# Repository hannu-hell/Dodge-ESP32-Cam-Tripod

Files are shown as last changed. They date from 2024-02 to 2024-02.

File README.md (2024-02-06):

# Dodge-ESP32-Cam-Tripod
Dodge is an ESP32 Cam based novel tripod design.  Feel free to check out full build instructions on Instructables website - https://www.instructables.com/Dodge-ESP32-Cam-Based-Tripod/

## Setting Neutral Position for all six servos
You need to get the neutral positions for all servos set before uploading the code for Dodge to move correctly.  I have included an image with Dodge in its neutral position and the angles the servos should be at those positions.
Once done with setting the neutral angles the rest of the moves by Dodge will be calculated correctly.

<ins><strong>Right Leg Top Servo (rAT)</strong></ins>\
GPIO Pin - IO 12\
Neutral Position - 60 degrees\
Leg Upwards - Increase degrees\
Leg Downwards - Decrease degrees

<ins><strong>Left Leg Top Servo (lAT)</strong></ins>\
GPIO Pin - IO 13\
Neutral Position - 105 degrees\
Leg Upwards - Decrease degrees\
Leg Downwards - Increase degrees

<ins><strong>Right Leg Bottom Servo (rAB)</strong></ins>\
GPIO Pin - IO 14\
Neutral Position - 90 degrees\
Leg Upwards - Increase degrees\
Leg Downwards - Decrease degrees

<ins><strong>Left Leg Bottom Servo (lAB)</strong></ins>\
GPIO Pin - IO 15\
Neutral Position - 95 degrees\
Leg Upwards - Decrease degrees\
Leg Downwards - Increase degrees

<ins><strong>Pinion Servo (mL)</strong></ins>\
GPIO Pin - IO 2\
Neutral Position - 107 degrees\
Leg Upwards - Decrease degrees\
Leg Downwards - Increase degrees

<ins><strong>Support Foot (bS)</strong></ins>\
GPIO Pin - IO 4\
Neutral Position - 90 degrees\
Rotation angle between 20 degrees and 180 degrees

## Uploading Code
When uploading code to the ESP32 Cam module you need the ESP32 Cam-MB which has the boot loader to upload code. You need to press the IO 0 button on the ESP32 Cam-MB and then the RST button on the ESP32 module to put the board to accept code uploads. Apart from that you will also need to download ESP32Servo library by Kevin Harrington/John K. Bennett from the Library manager in Arduino IDE.

## Powering up
In the code file update to your desired password to connect to Dodge and once the code has been uploaded you can see it visible as Dodge-Tripod on the WIFI network. After you upload the code make sure to reset the ESP32 Cam module by pressing the RST button on the back. Connect to Dodge-Tripod and then open up a browser and in the url enter 192.168.4.1 on your phone/computer to connect to the Dodge Control App. Make sure to power up the Primary and Secondary Batteries and then your good to go. Power on the primary battery by connecting the barrel jack and turning the small slide switch on the bottom of Dodge's head, and then you can power on the secondary battery by connecting the battery to the buck converter module.

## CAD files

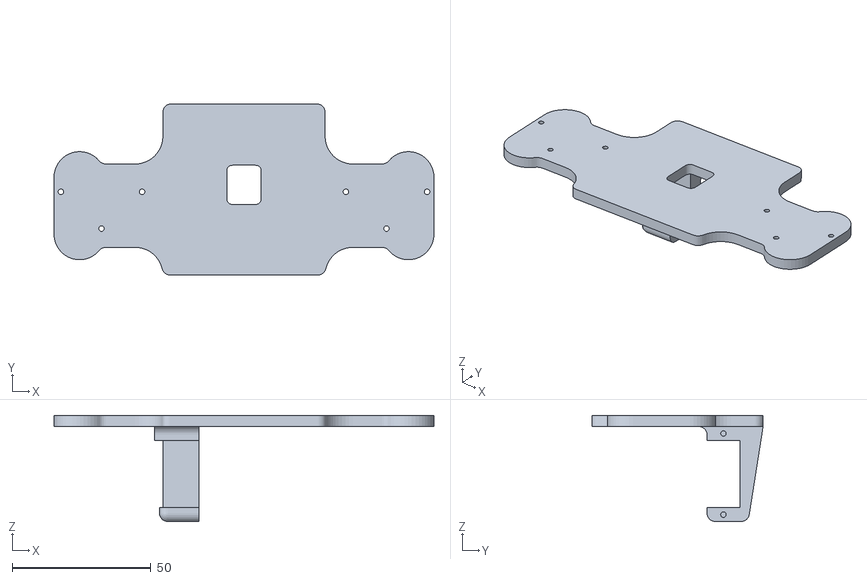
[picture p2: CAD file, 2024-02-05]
Top_Plate.stl
136.8 x 61.6 x 38.2

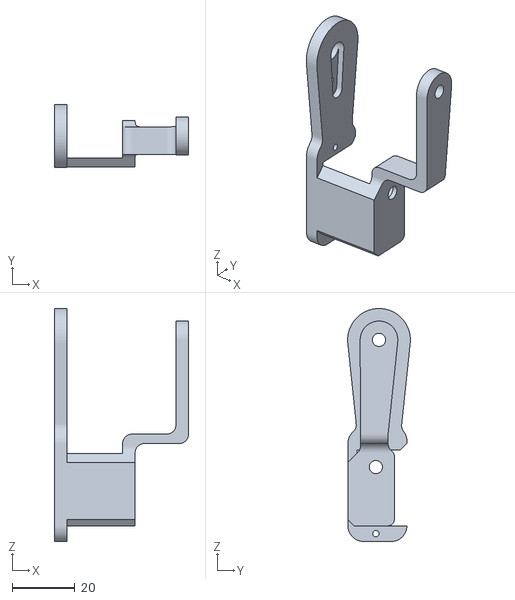
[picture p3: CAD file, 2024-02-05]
Upper_Leg.stl
42.7 x 20.0 x 74.2

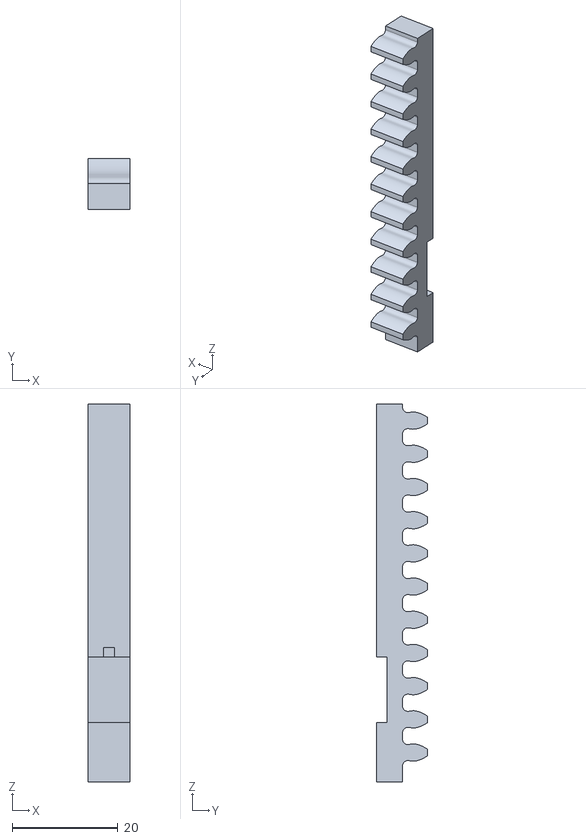
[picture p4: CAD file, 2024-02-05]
Rack.stl
8.00 x 9.72 x 71.5

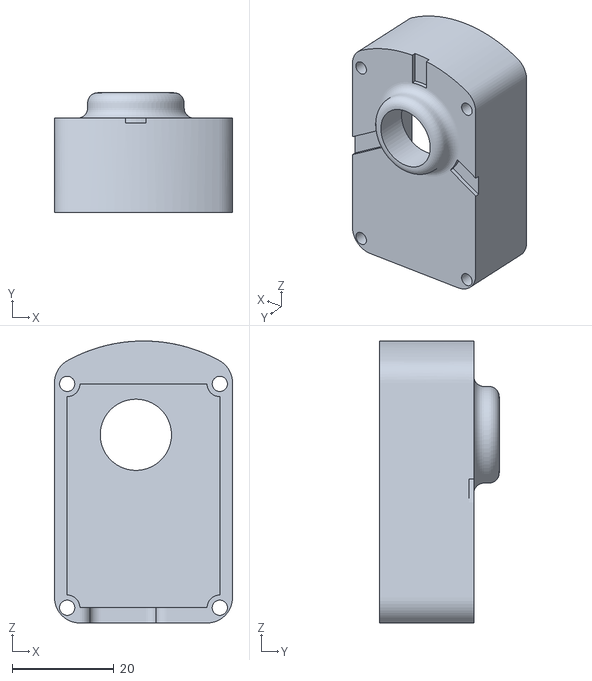
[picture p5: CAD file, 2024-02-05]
Head_Front.stl
35.0 x 23.5 x 55.4

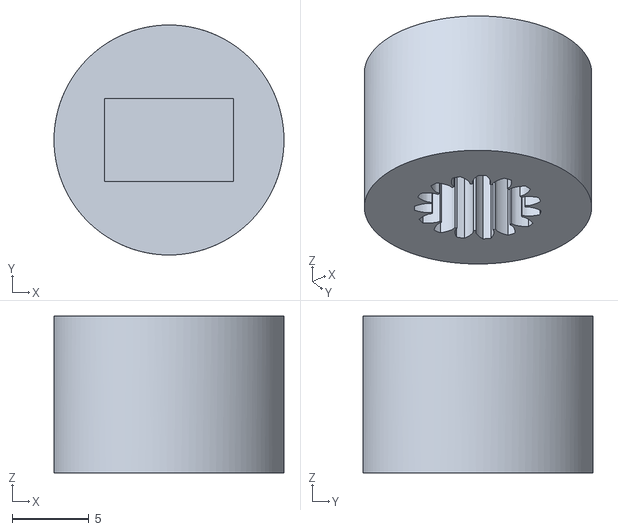
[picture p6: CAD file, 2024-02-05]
Collar.stl
15.0 x 15.0 x 10.2

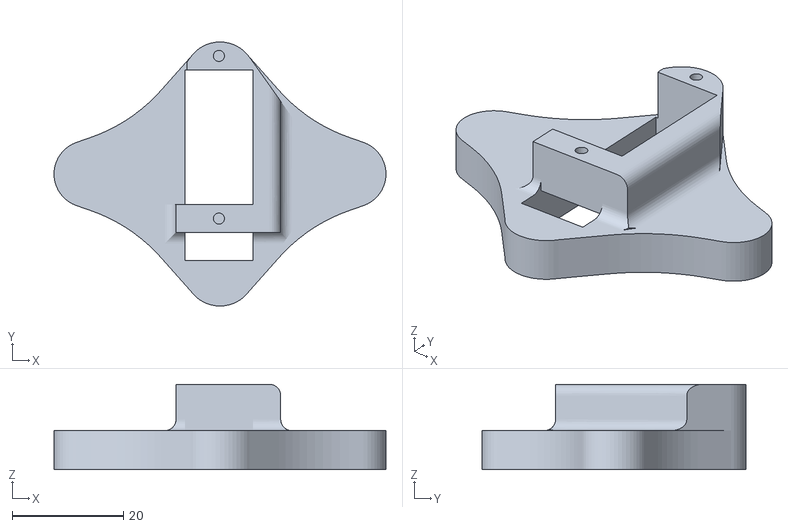
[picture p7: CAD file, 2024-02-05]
Support_Feet.stl
59.6 x 47.4 x 15.3

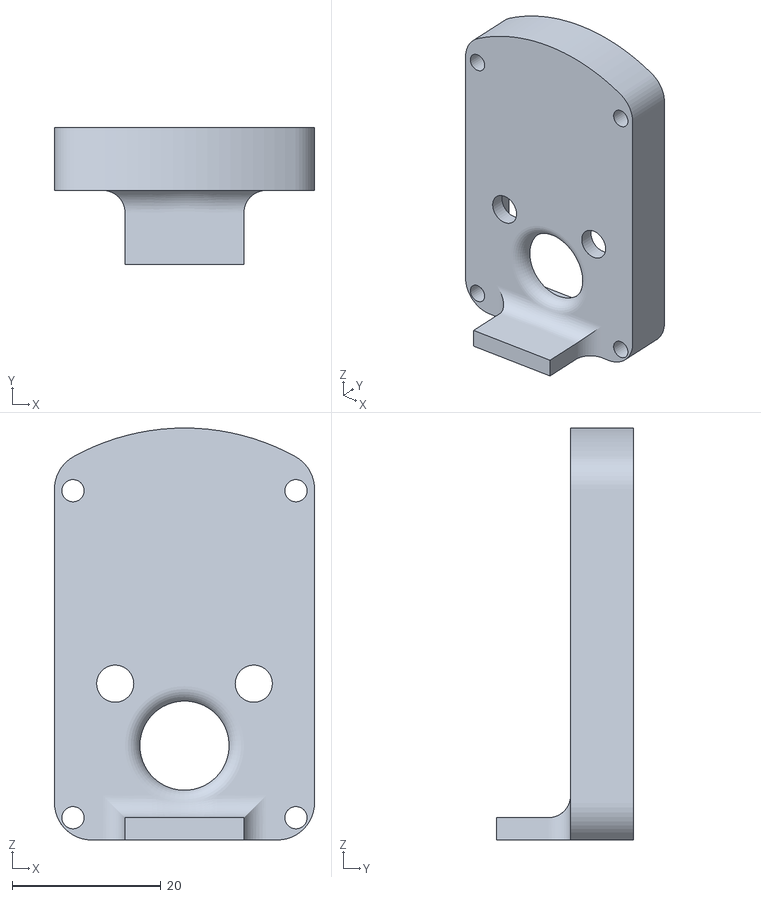
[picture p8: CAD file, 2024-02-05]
Head_Back.stl
35.0 x 18.5 x 55.4

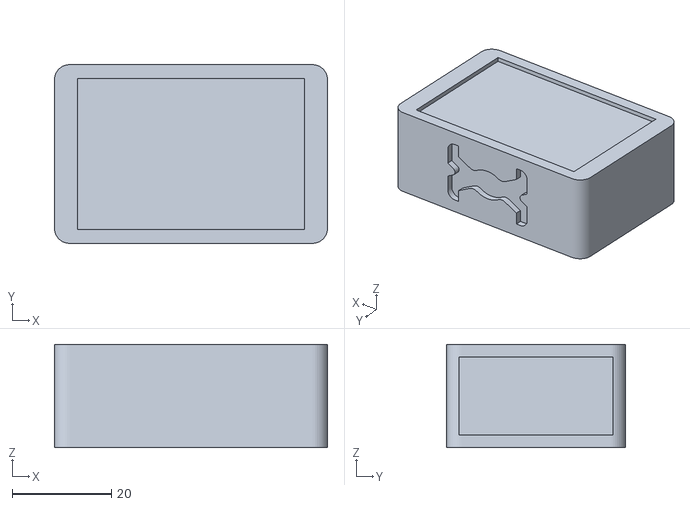
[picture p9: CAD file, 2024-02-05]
Battery_Compartment.stl
55.0 x 36.0 x 20.8

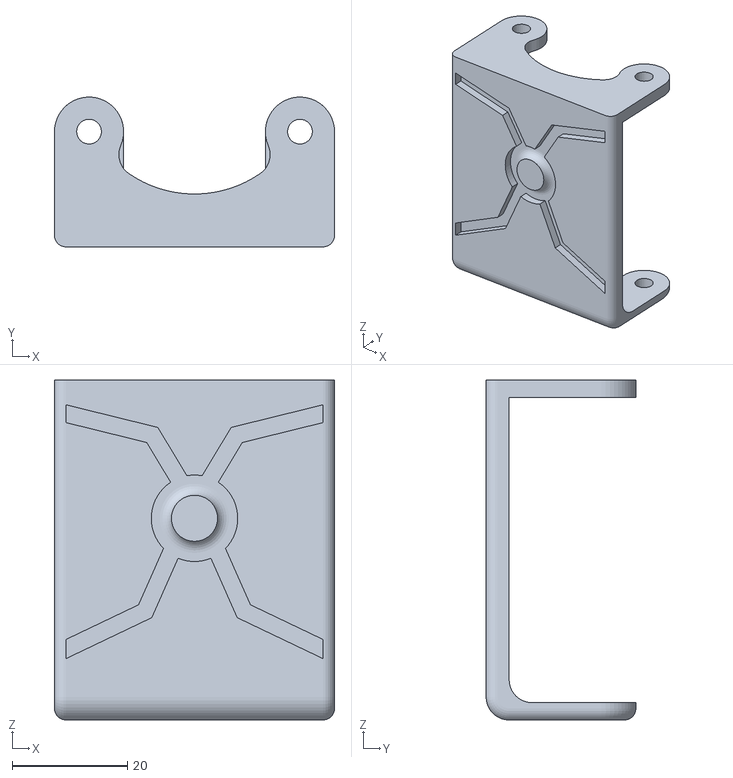
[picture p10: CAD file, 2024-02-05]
Bearing_Frame.stl
48.6 x 26.0 x 59.0

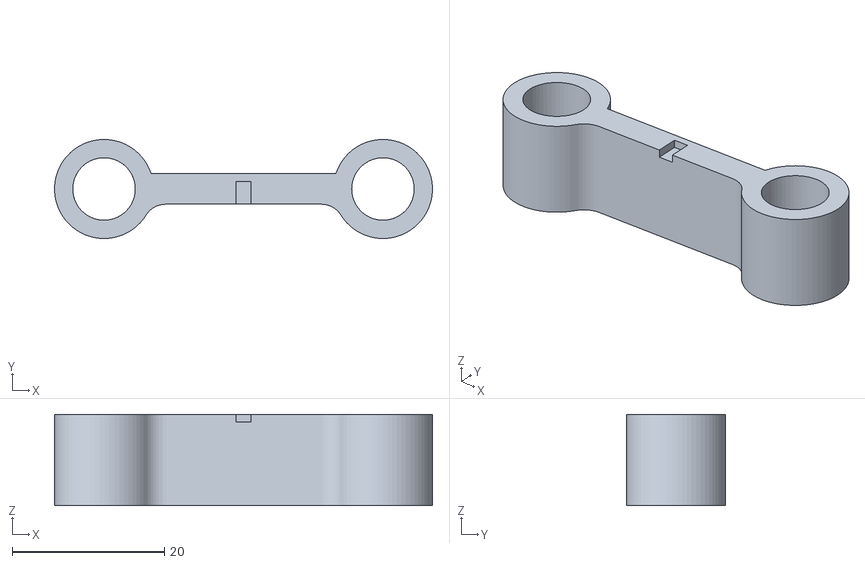
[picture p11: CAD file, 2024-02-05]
Bearing_Holder.stl
49.6 x 13.0 x 12.0

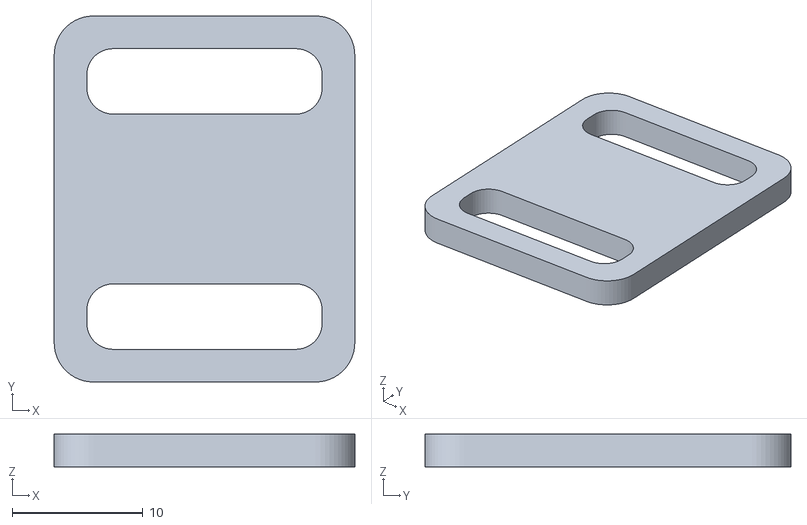
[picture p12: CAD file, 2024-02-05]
Buck_Casing_Lid.stl
23.0 x 28.0 x 2.50

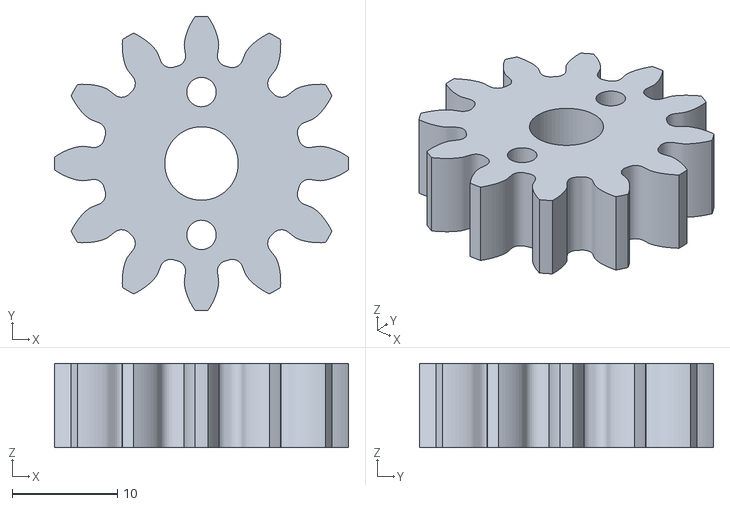
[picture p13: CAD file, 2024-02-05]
Pinion.stl
28.0 x 28.0 x 8.00

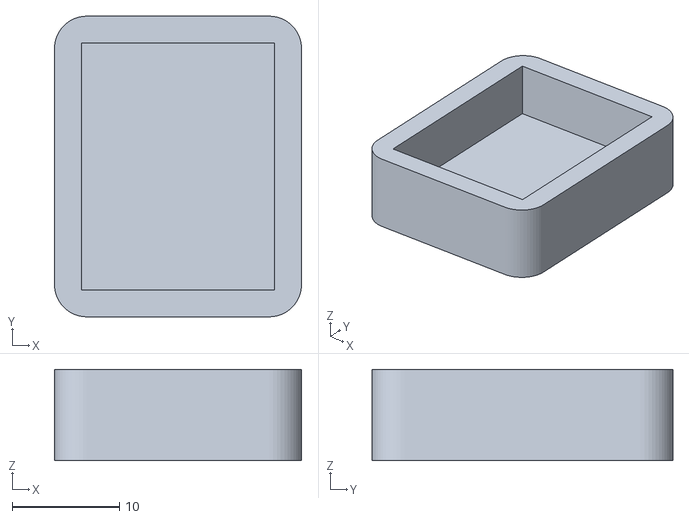
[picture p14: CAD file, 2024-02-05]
Buck_Convertor_Casing.stl
23.0 x 28.0 x 8.50

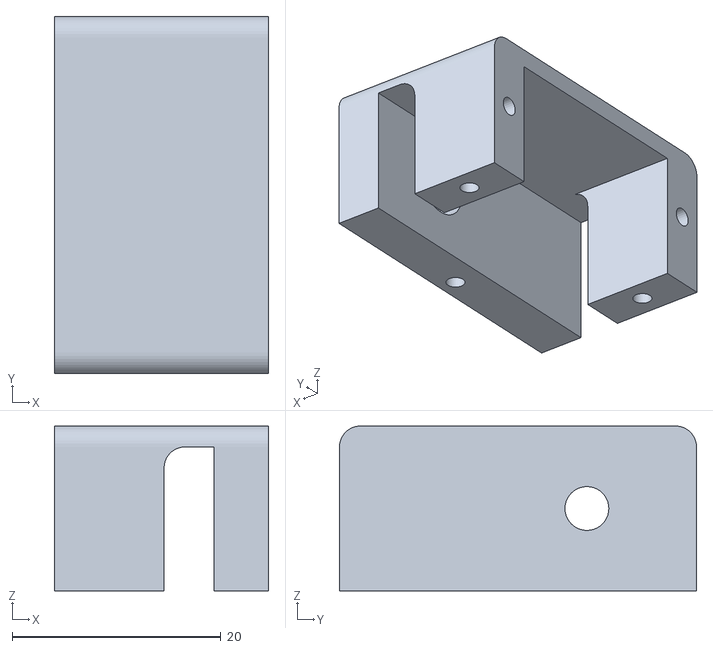
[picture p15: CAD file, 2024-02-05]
Left_Shoulder.stl
20.5 x 34.2 x 15.8

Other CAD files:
Feet.stl
Coupler_Gear.stl
Lower_Leg.stl
Primary_Battery_Compartment.stl
Right_Shoulder.stl

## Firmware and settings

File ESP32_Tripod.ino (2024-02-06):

#include "esp_camera.h"
#include <WiFi.h>
#include "esp_timer.h"
#include "img_converters.h"
#include "Arduino.h"
#include "fb_gfx.h"
#include "soc/soc.h"             // disable brownout problems
#include "soc/rtc_cntl_reg.h"    // disable brownout problems
#include "esp_http_server.h"
#include <ESP32Servo.h>

// Replace with your preffered password
const char* ssid = "Dodge-Tripod";
const char* password = "hannu1234";

#define PART_BOUNDARY "123456789000000000000987654321"

#define PWDN_GPIO_NUM     32
#define RESET_GPIO_NUM    -1
#define XCLK_GPIO_NUM      0
#define SIOD_GPIO_NUM     26
#define SIOC_GPIO_NUM     27

#define Y9_GPIO_NUM       35
#define Y8_GPIO_NUM       34
#define Y7_GPIO_NUM       39
#define Y6_GPIO_NUM       36
#define Y5_GPIO_NUM       21
#define Y4_GPIO_NUM       19
#define Y3_GPIO_NUM       18
#define Y2_GPIO_NUM        5
#define VSYNC_GPIO_NUM    25
#define HREF_GPIO_NUM     23
#define PCLK_GPIO_NUM     22

// Servo definitions

/* 
  bS -> Support Feet Base Servo
  rAT -> Right Leg Top Servo
  lAT -> Left Leg Top Servo
  rAB -> Right Leg Bottom Servo
  lAB -> Left Leg Bottom Servo
  mL -> Pinion Servo

*/

Servo bS;
Servo rAT;
Servo lAT;
Servo rAB;
Servo lAB;
Servo mL;


/* 
These are the neutral positions for the servos. The Upper (rAT and lAT) and Lower (rAB and LAB) Legs should be 90 degrees to the ground when set to these neutral positions (nRAT, nRAB, nLAT and nLAB).
The pinion servo angles should be mLD when lowered to its extreme (touching the ground) and mLU when raised to its upper limit (support foot raised up).  After you
adjust the servo positions to these angles the rest of the angles will be calculated accurately.
You can have a look at the image on this repo showing Dodge in its neutral position to have a clear idea. 
*/
int nRAT = 60;
int nRAB = 90;
int nLAT = 105;
int nLAB = 95;
int mLD = 165;
int mLU = 50;

int rotPos = 90;  // Rotation angle of the support foot servo
bool flip = false;
bool rightFlip = false;
bool leftFlip = true;
bool moveUp = false;
bool moveDown = false;
bool showMoves = false;

static const char* _STREAM_CONTENT_TYPE = "multipart/x-mixed-replace;boundary=" PART_BOUNDARY;
static const char* _STREAM_BOUNDARY = "\r\n--" PART_BOUNDARY "\r\n";
static const char* _STREAM_PART = "Content-Type: image/jpeg\r\nContent-Length: %u\r\n\r\n";

httpd_handle_t camera_httpd = NULL;
httpd_handle_t stream_httpd = NULL;

static const char PROGMEM INDEX_HTML[] = R"rawliteral(
<html>
  <head>
    <title>ESP32-CAM Robot</title>
    <meta name="viewport" content="width=device-width, initial-scale=1">
    <style>
      body { font-family: Arial; text-align: center; margin:0px auto; padding-top: 30px;}
      table { margin-left: auto; margin-right: auto; }
      td { padding: 8 px; }
      .button {
        background-color: #2f4468;
        border: none;
        color: white;
        padding: 10px 20px;
        text-align: center;
        text-decoration: none;
        display: inline-block;
        font-size: 18px;
        margin: 6px 3px;
        cursor: pointer;
        -webkit-touch-callout: none;
        -webkit-user-select: none;
        -khtml-user-select: none;
        -moz-user-select: none;
        -ms-user-select: none;
        user-select: none;
        -webkit-tap-highlight-color: rgba(0,0,0,0);
      }
      img {  width: auto ;
        max-width: 100% ;
        height: auto ; 
      }
    </style>
  </head>
  <body>
    <h1>Dodge-Tripod</h1>
    <img src="" id="photo" >
    <table>
      <tr><td colspan="3" align="center"><button class="button" onmousedown="toggleCheckbox('up');" ontouchstart="toggleCheckbox('up');">Up</button></td></tr>
      <tr><td align="center"><button class="button" onmousedown="toggleCheckbox('left');" ontouchstart="toggleCheckbox('left');">Left</button></td><td align="center"></td><td align="center"><button class="button" onmousedown="toggleCheckbox('right');" ontouchstart="toggleCheckbox('right');">Right</button></td></tr>
      <tr><td colspan="3" align="center"><button class="button" onmousedown="toggleCheckbox('down');" ontouchstart="toggleCheckbox('down');">Down</button></td></tr>
      <tr><td align="center"><button class="button" onmousedown="toggleCheckbox('l-turn');" ontouchstart="toggleCheckbox('l-turn');">L-Turn</button></td><td align="center"></td><td align="center"><button class="button" onmousedown="toggleCheckbox('r-turn');" ontouchstart="toggleCheckbox('r-turn');">R-Turn</button></td></tr>
      <tr><td align="center"><button class="button" onmousedown="toggleCheckbox('moves');" ontouchstart="toggleCheckbox('moves');">Moves</button></td><td align="center"></td><td align="center"><button class="button" onmousedown="toggleCheckbox('flip');" ontouchstart="toggleCheckbox('flip');">Flip</button></td></tr>                  
    </table>
   <script>
   function toggleCheckbox(x) {
     var xhr = new XMLHttpRequest();
     xhr.open("GET", "/action?go=" + x, true);
     xhr.send();
   }
   window.onload = document.getElementById("photo").src = window.location.href.slice(0, -1) + ":81/stream";
  </script>
  </body>
</html>
)rawliteral";

static esp_err_t index_handler(httpd_req_t *req){
  httpd_resp_set_type(req, "text/html");
  return httpd_resp_send(req, (const char *)INDEX_HTML, strlen(INDEX_HTML));
}

static esp_err_t stream_handler(httpd_req_t *req){
  camera_fb_t * fb = NULL;
  esp_err_t res = ESP_OK;
  size_t _jpg_buf_len = 0;
  uint8_t * _jpg_buf = NULL;
  char * part_buf[64];

  res = httpd_resp_set_type(req, _STREAM_CONTENT_TYPE);
  if(res != ESP_OK){
    return res;
  }

  while(true){
    fb = esp_camera_fb_get();
    if (!fb) {
      Serial.println("Camera capture failed");
      res = ESP_FAIL;
    } else {
      if(fb->width > 400){
        if(fb->format != PIXFORMAT_JPEG){
          bool jpeg_converted = frame2jpg(fb, 80, &_jpg_buf, &_jpg_buf_len);
          esp_camera_fb_return(fb);
          fb = NULL;
          if(!jpeg_converted){
            Serial.println("JPEG compression failed");
            res = ESP_FAIL;
          }
        } else {
          _jpg_buf_len = fb->len;
          _jpg_buf = fb->buf;
        }
      }
    }
    if(res == ESP_OK){
      size_t hlen = snprintf((char *)part_buf, 64, _STREAM_PART, _jpg_buf_len);
      res = httpd_resp_send_chunk(req, (const char *)part_buf, hlen);
    }
    if(res == ESP_OK){
      res = httpd_resp_send_chunk(req, (const char *)_jpg_buf, _jpg_buf_len);
    }
    if(res == ESP_OK){
      res = httpd_resp_send_chunk(req, _STREAM_BOUNDARY, strlen(_STREAM_BOUNDARY));
    }
    if(fb){
      esp_camera_fb_return(fb);
      fb = NULL;
      _jpg_buf = NULL;
    } else if(_jpg_buf){
      free(_jpg_buf);
      _jpg_buf = NULL;
    }
    if(res != ESP_OK){
      break;
    }
  }
  return res;
}

static esp_err_t cmd_handler(httpd_req_t *req){
  char*  buf;
  size_t buf_len;
  char variable[32] = {0,};
  
  buf_len = httpd_req_get_url_query_len(req) + 1;
  if (buf_len > 1) {
    buf = (char*)malloc(buf_len);
    if(!buf){
      httpd_resp_send_500(req);
      return ESP_FAIL;
    }
    if (httpd_req_get_url_query_str(req, buf, buf_len) == ESP_OK) {
      if (httpd_query_key_value(buf, "go", variable, sizeof(variable)) == ESP_OK) {
      } else {
        free(buf);
        httpd_resp_send_404(req);
        return ESP_FAIL;
      }
    } else {
      free(buf);
      httpd_resp_send_404(req);
      return ESP_FAIL;
    }
    free(buf);
  } else {
    httpd_resp_send_404(req);
    return ESP_FAIL;
  }

  sensor_t * s = esp_camera_sensor_get();

  int res = 0;
  
  if(!strcmp(variable, "up")) {
    showMoves = false;
    if (moveUp == false){
      move_up();
    }
    
  }
  else if(!strcmp(variable, "left")) {
    showMoves = false;
    reset_vertical_move();
    walk_left();
  }
  else if(!strcmp(variable, "right")) {
    showMoves = false;
    reset_vertical_move();
    walk_right();
  }
  else if(!strcmp(variable, "l-turn")) {
    showMoves = false;
    reset_vertical_move();
    turn_left();
    flip = false;
  }
  else if(!strcmp(variable, "r-turn")) {
    showMoves = false;
    reset_vertical_move();
    turn_right();
    flip = false;
  }
  else if(!strcmp(variable, "down")) {
    showMoves = false;
    if (moveDown == false){
      move_down();
    }
    
  }
  else if(!strcmp(variable, "flip")) {
    showMoves = false;
    reset_vertical_move();
    if (flip == false){
      if (rightFlip){
        flip_right();
      }
      else {
      flip_left();
      }
    }
    
  }
  else if(!strcmp(variable, "moves")) {
    moveUp = false;
    moveDown = false;
    if (showMoves == false){
      show_moves();
    }
  }
  else {
    res = -1;
  }

  if(res){
    return httpd_resp_send_500(req);
  }

  httpd_resp_set_hdr(req, "Access-Control-Allow-Origin", "*");
  return httpd_resp_send(req, NULL, 0);
}

void startCameraServer(){
  httpd_config_t config = HTTPD_DEFAULT_CONFIG();
  config.server_port = 80;
  httpd_uri_t index_uri = {
    .uri       = "/",
    .method    = HTTP_GET,
    .handler   = index_handler,
    .user_ctx  = NULL
  };

  httpd_uri_t cmd_uri = {
    .uri       = "/action",
    .method    = HTTP_GET,
    .handler   = cmd_handler,
    .user_ctx  = NULL
  };
  httpd_uri_t stream_uri = {
    .uri       = "/stream",
    .method    = HTTP_GET,
    .handler   = stream_handler,
    .user_ctx  = NULL
  };
  if (httpd_start(&camera_httpd, &config) == ESP_OK) {
    httpd_register_uri_handler(camera_httpd, &index_uri);
    httpd_register_uri_handler(camera_httpd, &cmd_uri);
  }
  config.server_port += 1;
  config.ctrl_port += 1;
  if (httpd_start(&stream_httpd, &config) == ESP_OK) {
    httpd_register_uri_handler(stream_httpd, &stream_uri);
  }
}

void setup() {
  WRITE_PERI_REG(RTC_CNTL_BROWN_OUT_REG, 0); 
  
  bS.setPeriodHertz(50);    
  rAT.setPeriodHertz(50);
  lAT.setPeriodHertz(50);
  rAB.setPeriodHertz(50);
  lAB.setPeriodHertz(50);
  mL.setPeriodHertz(50);

  bS.attach(4, 500, 2500);
  rAT.attach(12, 500, 2500);
  lAT.attach(13, 500, 2500);
  rAB.attach(14, 500, 2500);
  lAB.attach(15, 500, 2500);
  mL.attach(2, 500, 2500);
  delay(2000);

  rAT.write(nRAT+36);
  rAB.write(nRAB-16);
  lAT.write(nLAT-36);
  lAB.write(nLAB+16);
  mL.write(165);
  
  camera_config_t config;
  config.ledc_channel = LEDC_CHANNEL_0;
  config.ledc_timer = LEDC_TIMER_0;
  config.pin_d0 = Y2_GPIO_NUM;
  config.pin_d1 = Y3_GPIO_NUM;
  config.pin_d2 = Y4_GPIO_NUM;
  config.pin_d3 = Y5_GPIO_NUM;
  config.pin_d4 = Y6_GPIO_NUM;
  config.pin_d5 = Y7_GPIO_NUM;
  config.pin_d6 = Y8_GPIO_NUM;
  config.pin_d7 = Y9_GPIO_NUM;
  config.pin_xclk = XCLK_GPIO_NUM;
  config.pin_pclk = PCLK_GPIO_NUM;
  config.pin_vsync = VSYNC_GPIO_NUM;
  config.pin_href = HREF_GPIO_NUM;
  config.pin_sscb_sda = SIOD_GPIO_NUM;
  config.pin_sscb_scl = SIOC_GPIO_NUM;
  config.pin_pwdn = PWDN_GPIO_NUM;
  config.pin_reset = RESET_GPIO_NUM;
  config.xclk_freq_hz = 20000000;
  config.pixel_format = PIXFORMAT_JPEG; 
  
  if(psramFound()){
    config.frame_size = FRAMESIZE_VGA;
    config.jpeg_quality = 10;
    config.fb_count = 2;
  } else {
    config.frame_size = FRAMESIZE_SVGA;
    config.jpeg_quality = 12;
    config.fb_count = 1;
  }
  
  // Camera init
  esp_err_t err = esp_camera_init(&config);
  if (err != ESP_OK) {
    Serial.printf("Camera init failed with error 0x%x", err);
    return;
  }

  WiFi.softAP(ssid, password);
  
  startCameraServer();
}

void loop() {

}

void reset_vertical_move(){
  moveUp = false;
  moveDown = false;
}

void flip_left(){
  mL.write(165);
  delay(200);
  rAB.write(nRAB-89);
  lAB.write(nLAB+89);
  rAT.write(nRAT+40);
  lAT.write(nLAT-40);
  delay(500);
  for (int i = rotPos; i>20; i--){
    bS.write(i);
    delay(15);
  }
  delay(1000);
  rAT.write(nRAT+36);
  lAT.write(nLAT-36);
  for (int i=1; i<74; i++){
    rAB.write(i);
    delay(5);
  }
  for (int i=184; i>111; i--){
    lAB.write(i);
    delay(5);
  }

  delay(1000);
  for (int i=165; i>49; i--){
    mL.write(i);
    delay(5);
  }
  delay(200);
  bS.write(180);
  delay(500);
  mL.write(165);
  rotPos = 180;
  leftFlip = true;
  rightFlip = false;
  flip = true;
}

void flip_right(){
  mL.write(165);
  delay(200);
  rAB.write(nRAB-89);
  lAB.write(nLAB+89);
  rAT.write(nRAT+40);
  lAT.write(nLAT-40);
  delay(500);
  for (int i=rotPos; i<181; i++){
    bS.write(i);
    delay(15);
  }
  delay(1000);
  rAT.write(nRAT+36);
  lAT.write(nLAT-36);
  for (int i=1; i<74; i++){
    rAB.write(i);
    delay(5);
  }
  for (int i=184; i>111; i--){
    lAB.write(i);
    delay(5);
  }
  delay(1000);
  for (int i=165; i>49; i--){
    mL.write(i);
    delay(5);
  }
  delay(1000);
  bS.write(20);
  delay(500);
  mL.write(165);
  rotPos = 20;
  leftFlip = false;
  rightFlip = true;
  flip = true;
}

void turn_left(){
  mL.write(165);
  delay(200);
  rAB.write(nRAB-89);
  lAB.write(nLAB+89);
  rAT.write(nRAT+40);
  lAT.write(nLAT-40);
  delay(500);
  if (rotPos > 20){
    for (int i=rotPos; i>rotPos-20; i--){
      bS.write(i);
      delay(15);
    }
    rotPos = rotPos - 20;
  }
}

void turn_right(){
  mL.write(165);
  delay(200);
  rAB.write(nRAB-89);
  lAB.write(nLAB+89);
  rAT.write(nRAT+40);
  lAT.write(nLAT-40);
  delay(500);
  if (rotPos < 180){
    for (int i=rotPos; i<rotPos+20; i++){
      bS.write(i);
      delay(15);
    }
    rotPos = rotPos + 20;
  }
}

void walk_left(){
  rAT.write(nRAT+36);
  rAB.write(nRAB-16);
  lAT.write(nLAT-36);
  lAB.write(nLAB+16);
  mL.write(155);
  delay(1000);
  for (int i=0; i<1; i++){
    rAT.write(nRAT+43);
    rAB.write(nRAB-54);

    delay(500);
    for (int i=155; i>60; i--){
      mL.write(i);
      delay(10);
    }

    delay(200);

    rAB.write(nRAB-16);
    lAB.write(nLAB+54);

    delay(500);
    for (int i=60; i<155; i++){
      mL.write(i);
      delay(10);
    }

    delay(500);
    lAT.write(nLAT-61);
    lAB.write(nLAB+43);
    delay(200);
    lAT.write(nLAT-36);
    lAB.write(nLAB+16);
    delay(200);
    rAT.write(nRAT+61);
    rAB.write(nRAB-43);
    delay(200);
    rAT.write(nRAT+36);
    rAB.write(nRAB-16);

  }
  
}

void walk_right(){
    rAT.write(nRAT+36);
    rAB.write(nRAB-16);
    lAT.write(nLAT-36);
    lAB.write(nLAB+16);
    mL.write(155);
    delay(1000);
  for (int i=0; i<1; i++){
    lAT.write(nLAT-43);
    lAB.write(nLAB+54);

    delay(500);
    for (int i=155; i>60; i--){
      mL.write(i);
      delay(10);
    }

    delay(200);

    lAB.write(nLAB+16);
    rAB.write(nRAB-54);

    delay(500);

    for (int i=60; i<155; i++){
      mL.write(i);
      delay(10);
    }

    delay(500);
    rAT.write(nRAT+61);
    rAB.write(nRAB-43);
    delay(200);
    rAT.write(nRAT+36);
    rAB.write(nRAB-16);
    delay(200);
    lAT.write(nLAT-61);
    lAB.write(nLAB+43);
    delay(200);
    lAT.write(nLAT-36);
    lAB.write(nLAB+16);
  }
}

void move_down(){
  rAT.write(nRAT+80);
  rAB.write(nRAB-45);
  lAT.write(nLAT-80);
  lAB.write(nLAB+45);
  delay(1000);
  for (int i=165; i>49; i--){
    mL.write(i);
    delay(10);
  }
  moveDown = true;
  moveUp = false;
}

void move_up(){
  rAT.write(nRAT+80);
  rAB.write(nRAB-45);
  lAT.write(nLAT-80);
  lAB.write(nLAB+45);
  delay(1000);
  for (int i=50; i<165; i++){
    mL.write(i);
    delay(10);
  }
  moveUp = true;
  moveDown = false;
}

void show_moves(){
  rAT.write(nRAT+36);
  rAB.write(nRAB-16);
  lAT.write(nLAT-36);
  lAB.write(nLAB+16);
  mL.write(165);
  delay(1000);
  for (int i=165; i<61; i--){
    mL.write(i);
    delay(10);
  }
  delay(500);
  bS.write(180);
  delay(1000);
  for (int i=60; i>165; i++){
    mL.write(i);
    delay(10);
  }
  delay(1000);
  rAT.write(nRAT+45);
  rAB.write(nRAB+85);
  lAT.write(nLAT-45);
  lAB.write(nLAB-85);
  delay(1000);
  for (int j=0; j<3; j++){
    for (int i=180; i>151; i--){
      bS.write(i);
      delay(10);
    }
    delay(200);
    for (int i=150; i<181; i++){
      bS.write(i);
      delay(10);
    }
    delay(200);
  }
  delay(1000);
  rAT.write(nRAT+75);
  rAB.write(nRAB-10);
  lAT.write(nLAT-75);
  lAB.write(nLAB+10);
  delay(1000);
  for (int j=0; j<3; j++){
    for (int i=105; i<121; i++){
      lAB.write(i);
      delay(15);
    }
    for (int i=30; i>10; i--){
      lAT.write(i);
      delay(15);
    }
    for (int i=120; i>105; i--){
      lAB.write(i);
      delay(15);
    }
    for (int i=9; i<31; i++){
      lAT.write(i);
      delay(15);
    }
    for (int i=135; i<155; i++){
      rAT.write(i);
      delay(15);
    }
    for (int i=80; i>65; i--){
      rAB.write(i);
      delay(15);
    }
    for (int i=155; i>136; i--){
      rAT.write(i);
      delay(15);
    }
    for (int i=64; i<81; i++){
      rAB.write(i);
      delay(15);
    }
    for (int i=30; i>10; i--){
      lAT.write(i);
      delay(15);
    }
    for (int i=120; i>105; i--){
      lAB.write(i);
      delay(15);
    }
    for (int i=9; i<31; i++){
      lAT.write(i);
      delay(15);
    }
    for (int i=105; i<121; i++){
      lAB.write(i);
      delay(15);
    }
    delay(300);
    rAT.write(nRAT+75);
    rAB.write(nRAB-10);
    lAT.write(nLAT-75);
    lAB.write(nLAB+10);
  }


  delay(1000);

  rAT.write(nRAT+75);
  rAB.write(nRAB+80);
  lAT.write(nLAT-75);
  lAB.write(nLAB+80);
  delay(500);
  for (int j=0; j<2; j++){
    for (int i=180; i>91; i--){
      bS.write(i);
      delay(15);
    }
    for (int i=90; i<181; i++){
      bS.write(i);
      delay(15);
    }
  }
  rAT.write(nRAT+75);
  rAB.write(nRAB-10);
  lAT.write(nLAT-75);
  lAB.write(nLAB+10);

  delay(1000);

  rAT.write(nRAT+36);
  rAB.write(nRAB-16);
  lAT.write(nLAT-36);
  lAB.write(nLAB+16);
  mL.write(165);
  delay(1000);
  for (int i=165; i>61; i--){
    mL.write(i);
    delay(10);
  }
  delay(500);
  bS.write(20);
  delay(1000);
  for (int i=60; i<165; i++){
    mL.write(i);
    delay(10);
  }
  delay(1000);
  rAT.write(nRAT+75);
  rAB.write(nRAB-80);
  lAT.write(nLAT-75);
  lAB.write(nLAB-80);
  delay(500);
  for (int j=0; j<2; j++){
    for (int i=20; i<111; i++){
      bS.write(i);
      delay(15);
    }
    for (int i=110; i>21; i--){
      bS.write(i);
      delay(15);
    }
  }
  delay(1000);
  for (int i=15; i<111; i++){
    lAB.write(i);
    delay(10);
  }
  for (int i=10; i<74; i++){
    rAB.write(i);
    delay(10);
  }
  for (int i=30; i<69; i++){
    lAT.write(i);
    delay(10);
  }
  for (int i=135; i>96; i--){
    rAT.write(i);
    delay(10);
  }
  rAT.write(nRAT+36);
  rAB.write(nRAB-16);
  lAT.write(nLAT-36);
  lAB.write(nLAB+16);
  delay(1000);
  for (int i=165; i>61; i--){
    mL.write(i);
    delay(10);
  }
  delay(500);
  bS.write(180);
  delay(1000);
  for (int i=60; i<165; i++){
    mL.write(i);
    delay(10);
  }
  showMoves = true;
}

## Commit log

2024-02-05 Add files via upload
    Arduino Code for Dodge
2024-02-05 Add files via upload
    3D Model (STLs) for Dodge
    [Battery_Compartment.stl, Bearing_Frame.stl, Bearing_Holder.stl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]
2024-02-06 Dodge Neutral Position For Servos
